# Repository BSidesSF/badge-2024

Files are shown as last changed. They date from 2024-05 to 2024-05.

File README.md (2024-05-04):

# BSidesSF 2024 Badge

| [Readme](README.md) | [Using the Badge](docs/BADGE.md) | [Playing the Game](docs/GAME.md) | [Software Development](docs/DEVELOP.md) | [Badge Hardware](docs/HARDWARE.md) |
| --- | --- | --- | --- | --- |

## Badge Game

The 2024 BSidesSF Badge is designed for playing the Attribution Game.
Similar to the board game Clue or some versions of Carmen Sandiego,
you need to figure out who the threat actor, attack tool, and victim
are for each round of the game. You do this by trading cards (or
'clues') as well as your self-entered alibi name with others
at the conference.

## Attribution Game basics

In order to play in the Attribution Game, you will need to enter a name or handle when you first turn on your badge. This will stay through power cycles. It can be cleared in your settings which will force you to enter a new one.

To trade cards with someone, scroll left or right until you get to the "BSidesSF '24" screen.
Once there, press the toggle up, and place your badge edge at the top of the screen against
the same badge edge of the person you are trading with. You should see once your card has
been transmitted and you have received a card from them.

You can check your collected cards by scrolling right from the "Badge '24" screen.

When you collect enough cards, the one remaining is the solution that completes the phrase. There are 6 games to play through - try them all!

Please see [Playing the Game](docs/GAME.md) for more details

## Repo Contents

This repository contains the hardware and software for
the badge and game. We hope it is useful for those who wish to hack
the badges and game, anyone who wants to use the badge to learn some
circuitpython, as well as others who might like to reuse some or all
of it for other projects.

The badge hardware was designed and produced by @securityfitz, as a favor to BSidesSF using a Labscon badge as a base design.
Ths badge software is a fork of the Labscon badge software, further mangled by @rlc4, @lanrat, and @securelyfitz

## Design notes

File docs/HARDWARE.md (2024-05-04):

# Hardware

| [Readme](../README.md) | [Using the Badge](BADGE.md) | [Playing the Game](GAME.md) | [Software Development](DEVELOP.md) | [Badge Hardware](HARDWARE.md) |
| --- | --- | --- | --- | --- |

`/hardware/` contains the kicad board design files and full details about
design and manufacturing. The hardware on the badge includes:

-  Raspberry Pi 2040, derived from the seeed xiao 2040
-  16MB spi flash for code and files
-  128x64 OLED display with SH1106 controller over I2C
-  IRDA PHY used directly on UART.
-  5-way d-pad for input
-  2 neopixel LEDs
-  AA battery plus boost voltage converter
-  USB-C connector plus vreg for usb power
-  power switch to switch between USB and Battery power
-  test points for reset, boot, and swd

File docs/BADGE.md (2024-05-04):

# Using the Badge

| [Readme](../README.md) | [Using the Badge](BADGE.md) | [Playing the Game](GAME.md) | [Software Development](DEVELOP.md) | [Badge Hardware](HARDWARE.md) |
| --- | --- | --- | --- | --- |

## Setup

When you first power on your badge it will give you a brief intro to
the badge and the game, then it will ask you for your contact info.
This could be a handle, email address, or any other string that will
be shared with everyone you interact with. Use the up and down but
tons to choose letters, left and right to move through the string,
and press the button to set your name. (it can be changed later)

## Navigating

- Left and Right switches between:
  - Home page
  - Alibis page, which shows all the people you've traded contact info and clues with
  - Clues page, which shows all the cards you've collected so far
  - Settings, which allow you to change badge features
- Up takes you to trade mode, described below
- Down puts the badge to sleep, which also happens automatically after a few
   seconds
- Pressing the center button usually gives you more details about whatever you're highlighting.

### Trading

Your badge has an infrared transceiver. Press the 'up' button to enter trade mode.
The badge will:

- transmit your clue as well as your contact information
- listen to receive someone elses card and contact info
- verify the cryptographic signature on the clue
- tell you the result of the trade.
  After the trade, you should be able to see the information in your Contacts an
  Cards pages.

### Winning

The real prize isn't attribution but the contacts and friends we made along the way.
If you happen to have collected enough info to attribute the attack, your badge will
tell you. Find a game organizer to validate your win.

### Multiple rounds

The first round of the game will be pretty easy with only a few trades needed to
attribute. Once a game is complete, the game controller will transmit a packet to
advance the game to the next round, which will propagate to everyone when they
trade clues. Each round will have a different set of cards/clues and a different
attack to attribute.

## After the conference

This badge can work as a simple circuitpython learning platform. The best source
of information about circuitpython is available on Adafruit, including a [Welcome
to CircuitPython guide](https://learn.adafruit.com/welcome-to-circuitpython/overview)

The best place to start tinkering is probably with some neat light animations on
the RGB LED on the badge. Adafruit
[has an example](https://github.com/adafruit/Adafruit_Learning_System_Guides/blob/main/Welcome_to_CircuitPython/code.py)
on how to use this RGB LEDs.

For working interactively with a python CLI, plug your badge in with a USB cable,
and connect to the serial port that shows up.

For writing your own circuitpython programs, you need to modify the code.py
file you can find on the drive that shows up when you plug in the USB cable.
Every time you save the file, the board will reset and start running your code.

If you've somehow messed up your badge, you can follow the process below to
flash a fresh copy of circuitpython and/or the game code.

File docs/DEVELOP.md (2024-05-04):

# Develop with BSidesSF Badge 2024

| [Readme](../README.md) | [Using the Badge](BADGE.md) | [Playing the Game](GAME.md) | [Software Development](DEVELOP.md) | [Badge Hardware](HARDWARE.md) |
| --- | --- | --- | --- | --- |

## Developing for the badge

Version: CircuitPython 9.0.4; Seeeduino XIAO RP2040

Make sure you use version compatible libraries

### Installing CircuitPython

When the RP2040 boots, it checks for valid data in the spi flash. If it doesn't,
it boots into USB boot-loader mode and shows up as a drive labeled RPI-RP2.
[Download and copy the .UF2 file](https://circuitpython.org/board/seeeduino_xiao_rp2040/)
to the drive and it will reboot into CircuitPython.
If you need to reinstall for any reason, short the 'BOOT' test pads while resetting
the RP2040 and it will go back to the boot-loader mode.

### Installing The Attribution Game

Once CircuitPython is installed, when the badge is plugged in it will show
both a serial port and a drive labeled CIRCUITPY. Copy the entire contents
of `/software/` in this repository to that drive. the badge will reboot and run the code.

### Provisioning the game data

The `/config/` directory contains some text files with data specific to
the game. These will be copied along with the rest of the code:

- genfiles generates a pair of keys, and creates 50 variations of game*.csv files
- game*.csv has all the possible clues for each game, and is provisioned with one signed clue per game
- seed.txt needs to be filled with a seed for the random choice of solutions
- priv.json and pub.json are generated by genfiles and contain the game keys which can be used to authenticate the signed
  clues you receive. This is generated by the controller, the public key is copied to all badges

Details about the hardware can be found in [HARDWARE](docs/HARDWARE.md)

## Software

- `/software/` contains the code on the badge
- `/flash/` contains files and tools for automatically flashing badges
- `/config/` contains tools to generate all of the encrypted badge configurations

### Architecture

Most functions are wrapped inside classes with the priority to make the top level
code more clean and readable versus sticking to a clean object model.

All functions should be non-blocking and quick to make sure the UI doesn't get
frozen and button presses don't get missed. This means stuff like checking for
enough UART valid data before reading it, and scheduling timed actions based on
timestamps instead of sleep() calls

#### Dependencies

- core circuitpython libraries: time,board,busio,pulseio,digitalio,displayio,
  terminalio
- additional adafruit libraries in `/software/lib/`: debouncer,
  ticks, displayio_ssh1106, imageload, display_text

#### Support modules

-  Fake_IRDA.py wraps the UART interface, handles enabling/disabling the
   IRDA enable pin, and stuffing/unstuffing the bytes that are transmitted
   to work with the IRDA phy in the nonstandard way we use it
-  Five_Way_Dpad.py wraps the dpad with the Adafruit Debouncer including
   all setup and a few helper functions for checking all buttons at once. The
   non-blocking update() function needs to be run periodically to capture all
   button presses.
-  sh1106_ui.py/ssd1306.py wraps the I2C display interface, handles the overall display
   view, and creates a separate group for each of the navigation pages. The
   non-blocking show() function should be called periodically to make sure the
   correct view is displayed and to manage the transition animations
-  disp.py wraps the functionality of the pages. The class handles initialization,
   managing the display view, underlying data and operations. Most of this is
   handled in a non-blocking update() function that returns the next state

## Screen

* https://www.arduino.cc/reference/en/libraries/oled-ssd1306-sh1106/
* https://docs.circuitpython.org/projects/displayio_sh1106/en/latest/api.html

Driven by: https://docs.circuitpython.org/en/latest/shared-bindings/displayio/

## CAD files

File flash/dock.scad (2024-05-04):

/* badge programming dock
right now, only a few parameters for making a multi-dock
can be mounted with M.3 screws and bolts
USB held in place with M.2 set screw

todo: more parameters; upright orientation; badge origin at usb port; dock base at z=0; round corners
*/

xpitch=10;
ypitch=20;
zpitch=70;
rows=7;
cols=1;
//wall_thickness=2
//badgex=
//badgey=
//badgez=

module badge(){
    union(){
        //pcb edge track
        linear_extrude(68)
        polygon(points=[
        [0,0],
        [126,0],
        [126,100],
        [28,2],
        [0,2]
        ]);
        //battery cutout
        translate([0,-3,4])
            cube([126,23,60]);        
        //usb port
        translate([-80,0.5,34-5.5])
            cube([80,6.5,11]);
        //power switch
        translate([-2,0,45])
            cube([2,5,5]);
        //usb set screw
        screwhole([-6,15,34],[90,0,0],6.5,3);
        //mounting holes
//        screwholes();
        }
}

module badgearray(rows=1,cols=1){
  for (i=[0:rows-1])
    for (j=[0:cols-1])
      translate([-i*xpitch,i*ypitch,j*zpitch])
    badge();
}

module screwhole(origin,orientation,d1=7,d2=4){
  translate(origin)
    rotate(orientation){
      //larger hex inset hole for head/bolt
      cylinder(h=6, d=d1,center=true,$fn=6);
      //smaller hole for shaft
      cylinder(h=100, d=d2,center=true,$fn=12);
    }
}

module screwholes(){
    //bottom
    screwhole([0,10,14],[0,90,0]);
    screwhole([0,10,68-14],[0,90,0]);
    //left
    screwhole([25,10,4],[0,0,0]);
    screwhole([5,10,4],[0,0,0]);
    //right
    screwhole([25,10,64],[0,0,0]);
    screwhole([5,10,64],[0,0,0]);
}

module multibadgedock(rows=1,cols=1){
  difference(){
    union(){
      translate([0,-2,-2])
        linear_extrude(zpitch*cols+2)
          polygon(points=[
            [45,0],
            [-rows*xpitch,0],
            [-rows*xpitch,ypitch*rows-1],
            [45-rows*xpitch,ypitch*rows-1]
          ]);
    }
    //carve out the badges
    badgearray(rows,cols);
    //clip the pointy top
    translate([43,-2,-2])cube([10,10,zpitch*cols+4]);
  }
}

single=true;
single=false;
dock=true;
//dock=false;

if (single){rows=1;cols=1;}
if (dock){
    multibadgedock(rows,cols);
}else{
    badgearray(rows,cols);
}

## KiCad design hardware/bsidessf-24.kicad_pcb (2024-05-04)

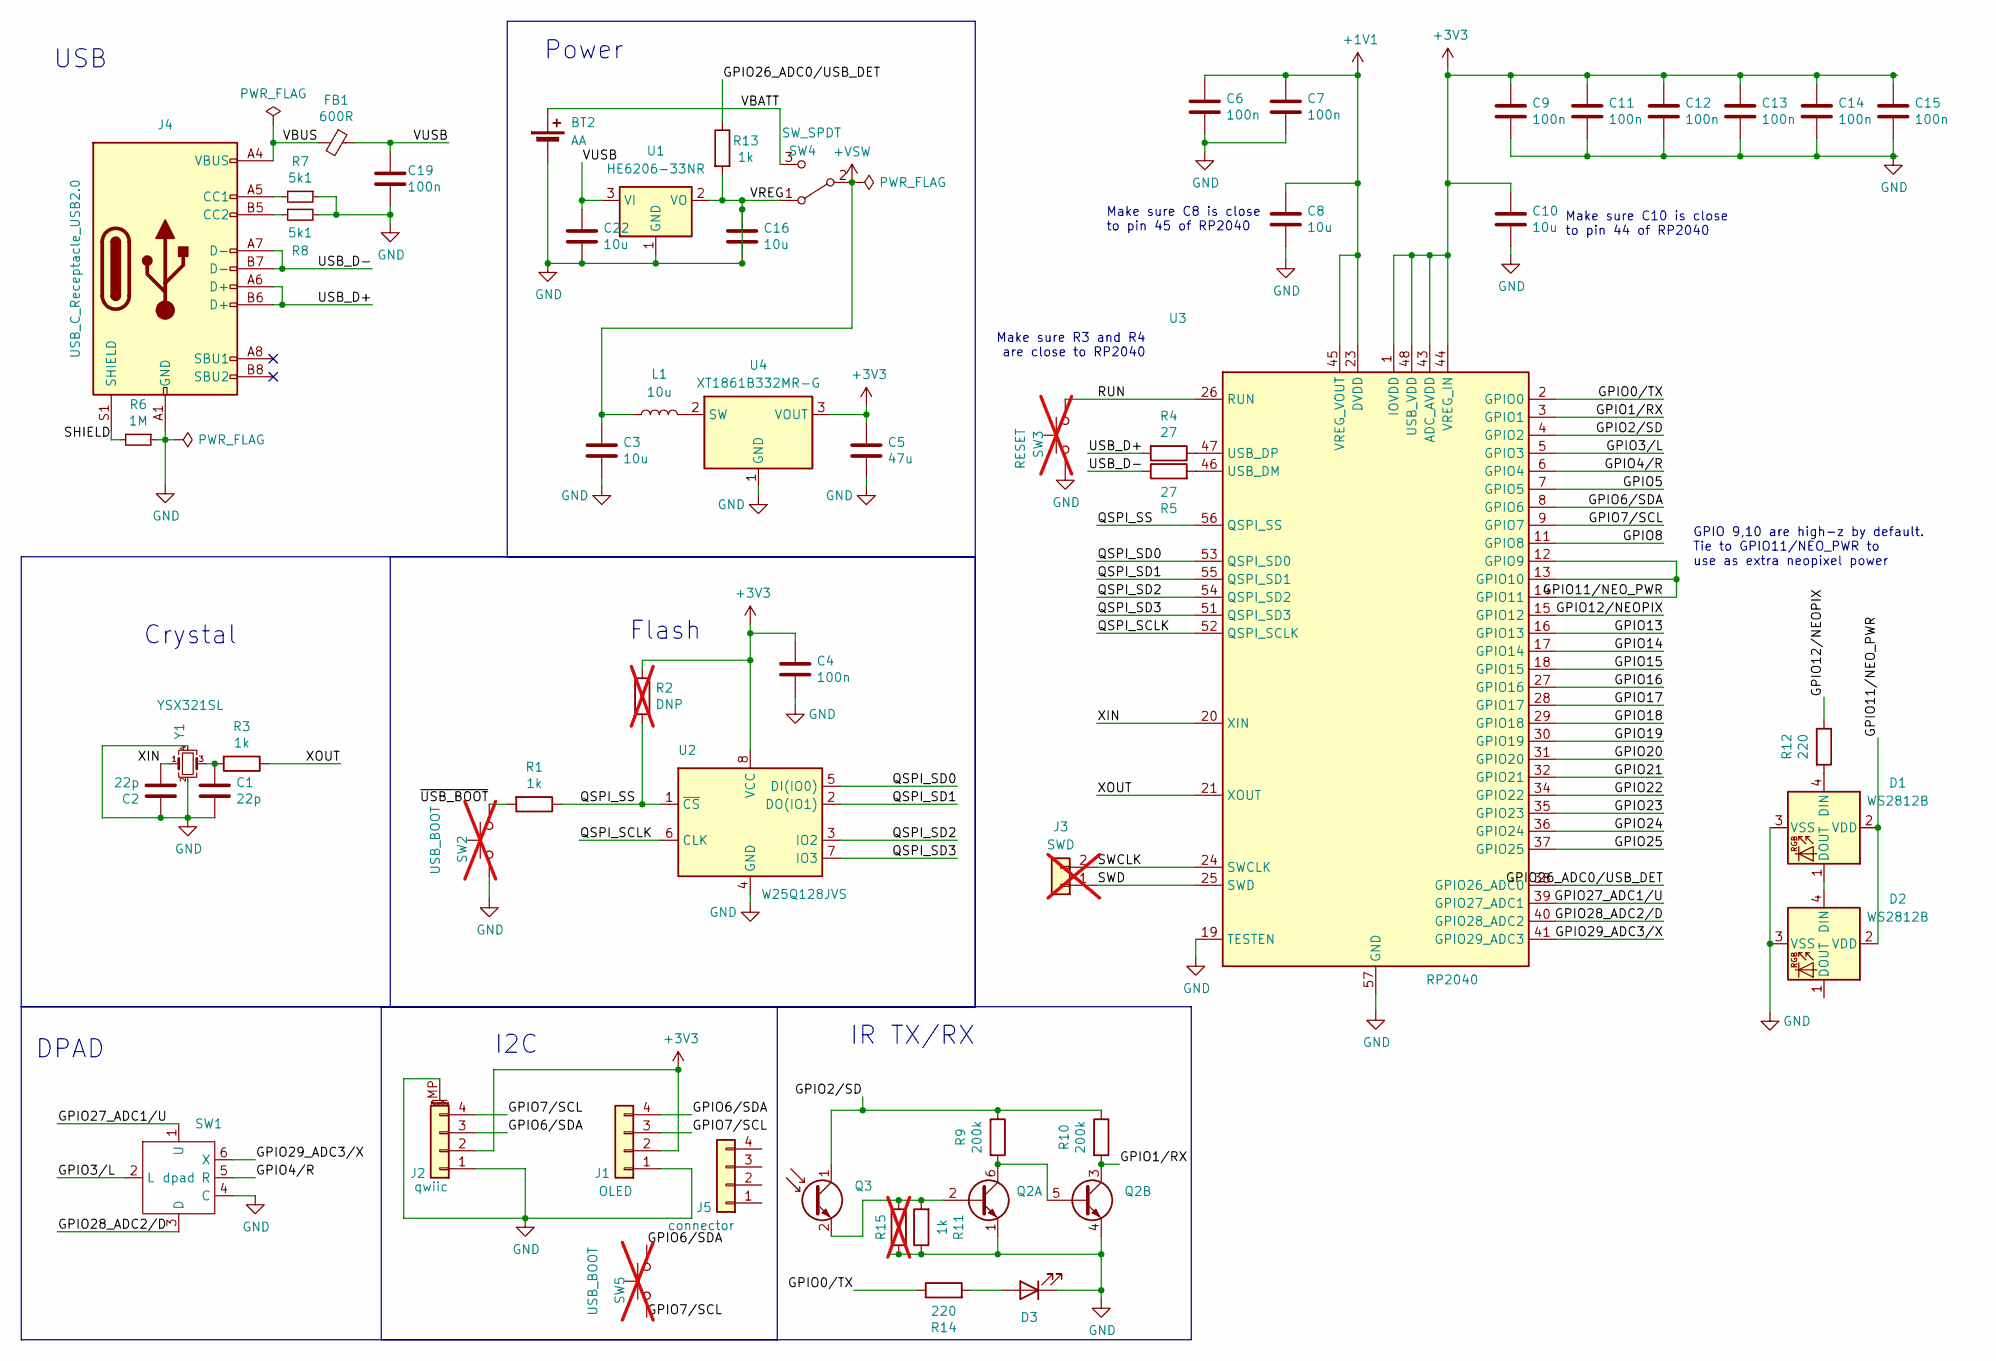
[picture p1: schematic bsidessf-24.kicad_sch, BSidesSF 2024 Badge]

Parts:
BT2: AA; BatteryHolder_Keystone_2460_1xAA; LCSC C5290181
C1, C2: 22p; C_0402_1005Metric; LCSC C106203
C3, C8, C10, C16, C22: 10u; C_0402_1005Metric; LCSC C15525
C4, C6, C7, C9, C11, C12, C13, C14, C15, C19: 100n; C_0402_1005Metric; LCSC C100072
C5: 47u; C_0805_2012Metric; LCSC C16780
D1, D2: WS2812B; LED_WS2812B_PLCC4_1.0x1.0mm; LCSC C5349953
D3: IR12-21C/TR8; IR12-21C-TR8; LCSC C53672
FB1: 600R; L_0402_1005Metric; LCSC C76886
J1: OLED; PinHeader_1x04_P2.54mm_Vertical; LCSC C5248080
J2: qwiic; JST_SH_SM04B-SRSS-TB_1x04-1MP_P1.00mm_Horizontal; LCSC C7433425
J3: SWD; SolderJumper-2_P1.3mm_Open_RoundedPad1.0x1.5mm; LCSC DNP; not fitted
J4: USB_C_Receptacle_USB2.0; USB_C_Receptacle_HRO_TYPE-C-31-M-12; LCSC C2927038
J5: connector; PinHeader_1x04_P2.54mm_Vertical; LCSC C2902691
L1: 10u; L_1008_2520Metric; LCSC C602018
Q2: BC847BS; SOT-363_SC-70-6; LCSC C5380687
Q3: PT12-21B/TR8; PT12-21B-TR8; LCSC C264383
R1, R3, R11, R13: 1k; R_0402_1005Metric; LCSC C11702
R2, R15: DNP; R_0402_1005Metric; LCSC DNP; not fitted
R4, R5: 27; R_0402_1005Metric; LCSC C25100
R6: 1M; R_0402_1005Metric; LCSC C26083
R7, R8: 5k1; R_0402_1005Metric; LCSC C25941
R9, R10: 200k; R_0402_1005Metric; LCSC C25764
R12, R14: 220; R_0402_1005Metric; LCSC C25091
SW1: dpad; 10x10x10x9-6P-WX; LCSC C2858290
SW2, SW5: USB_BOOT; SolderJumper-2_P1.3mm_Open_RoundedPad1.0x1.5mm; LCSC DNP; not fitted
SW3: RESET; SolderJumper-2_P1.3mm_Open_RoundedPad1.0x1.5mm; LCSC DNP; not fitted
SW4: SW_SPDT; SW_SPDT_PCM12; LCSC C319020
U1: HE6206-33NR; SOT-23-3; LCSC C5199441
U2: W25Q128JVS; SOIC-8_5.23x5.23mm_P1.27mm; LCSC C97521
U3: RP2040; QFN-56-1EP_7x7mm_P0.4mm_EP3.2x3.2mm; LCSC C2040
U4: XT1861B332MR-G; SOT-23; LCSC C236396
Y1: YSX321SL; Crystal_SMD_3225-4Pin_3.2x2.5mm; LCSC C9002

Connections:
+1V1: C6.1, C7.1, C8.1, U3.23 (DVDD), U3.45 (VREG_VOUT), U3.50 (DVDD)
+3V3: C4.1, C5.1, C9.1, C10.1, C11.1, C12.1, C13.1, C14.1, C15.1, J1.2, J2.2, R2.1, U2.8 (VCC), U3.1 (IOVDD), U3.10 (IOVDD), U3.22 (IOVDD), U3.33 (IOVDD), U3.42 (IOVDD), U3.43 (ADC_AVDD), U3.44 (VREG_IN), U3.48 (USB_VDD), U3.49 (IOVDD), U4.3 (VOUT)
+VSW: C3.1, L1.1, SW4.2 (B)
/GPIO0/TX: R14.1, U3.2 (GPIO0)
/GPIO1/RX: Q2.3 (C2), R10.2, U3.3 (GPIO1)
/GPIO2/SD: Q3.1 (C), R9.1, R10.1, U3.4 (GPIO2)
/GPIO3/L: SW1.2 (L), U3.5 (GPIO3)
/GPIO4/R: SW1.5 (R), U3.6 (GPIO4)
/GPIO5: U3.7 (GPIO5)
/GPIO6/SDA: J1.4, J2.3, SW5.1, U3.8 (GPIO6)
/GPIO7/SCL: J1.3, J2.4, SW5.2, U3.9 (GPIO7)
/GPIO8: U3.11 (GPIO8)
/GPIO11/NEO_PWR: D1.2 (VDD), D2.2 (VDD), U3.12 (GPIO9), U3.13 (GPIO10), U3.14 (GPIO11)
/GPIO12/NEOPIX: R12.1, U3.15 (GPIO12)
/GPIO13: U3.16 (GPIO13)
/GPIO14: U3.17 (GPIO14)
/GPIO15: U3.18 (GPIO15)
/GPIO16: U3.27 (GPIO16)
/GPIO17: U3.28 (GPIO17)
/GPIO18: U3.29 (GPIO18)
/GPIO19: U3.30 (GPIO19)
/GPIO20: U3.31 (GPIO20)
/GPIO21: U3.32 (GPIO21)
/GPIO22: U3.34 (GPIO22)
/GPIO23: U3.35 (GPIO23)
/GPIO24: U3.36 (GPIO24)
/GPIO25: U3.37 (GPIO25)
/GPIO26_ADC0/USB_DET: R13.1, U3.38 (GPIO26_ADC0)
/GPIO27_ADC1/U: SW1.1 (U), U3.39 (GPIO27_ADC1)
/GPIO28_ADC2/D: SW1.3 (D), U3.40 (GPIO28_ADC2)
/GPIO29_ADC3/X: SW1.6 (X), U3.41 (GPIO29_ADC3)
/QSPI_SCLK: U2.6 (CLK), U3.52 (QSPI_SCLK)
/QSPI_SD0: U2.5 (DI(IO0)), U3.53 (QSPI_SD0)
/QSPI_SD1: U2.2 (DO(IO1)), U3.55 (QSPI_SD1)
/QSPI_SD2: U2.3 (IO2), U3.54 (QSPI_SD2)
/QSPI_SD3: U2.7 (IO3), U3.51 (QSPI_SD3)
/QSPI_SS: R1.1, R2.2, U2.1 (~CS), U3.56 (QSPI_SS)
/RUN: SW3.1, U3.26 (RUN)
/SHIELD: J4.S1 (SHIELD), R6.2
/SWCLK: J3.2, U3.24 (SWCLK)
/SWD: J3.1, U3.25 (SWD)
/USB_D+: J4.A6 (D+), J4.B6 (D+), R4.2
/USB_D-: J4.A7 (D-), J4.B7 (D-), R5.1
/VBATT: BT2.1 (+), SW4.3 (C)
/VBUS: FB1.2, J4.A4 (VBUS), J4.A9 (VBUS), J4.B4 (VBUS), J4.B9 (VBUS)
/VREG: C16.1, R13.2, SW4.1 (A), U1.2 (VO)
/VUSB: C19.1, C22.1, FB1.1, U1.3 (VI)
/XIN: C2.2, U3.20 (XIN), Y1.1
/XOUT: R3.1, U3.21 (XOUT)
/~USB_BOOT: R1.2, SW2.1
GND: BT2.2 (-), C1.2, C2.1, C3.2, C4.2, C5.2, C6.2, C7.2, C8.2, C9.2, C10.2, C11.2, C12.2, C13.2, C14.2, C15.2, C16.2, C19.2, C22.2, D1.3 (VSS), D2.3 (VSS), D3.2 (K), J1.1, J2.1, J2.MP (MountPin), J4.A1 (GND), J4.A12 (GND), J4.B1 (GND), J4.B12 (GND), Q2.1 (E1), Q2.4 (E2), R6.1, R7.1, R8.2, R11.1, R15.1, SW1.4 (C), SW2.2, SW3.2, U1.1 (GND), U2.4 (GND), U3.19 (TESTEN), U3.57 (GND), U4.1 (GND), Y1.2, Y1.4
unnamed: C1.1, R3.2, Y1.3
unnamed: D1.4 (DIN), R12.2
unnamed: D1.1 (DOUT), D2.4 (DIN)
unnamed: D3.1 (A), R14.2
unnamed: J4.A5 (CC1), R7.2
unnamed: J4.B5 (CC2), R8.1
unnamed: Q2.2 (B1), Q3.2 (E), R11.2, R15.2
unnamed: Q2.5 (B2), Q2.6 (C1), R9.2
unnamed: R5.2, U3.46 (USB_DM)
unnamed: R4.1, U3.47 (USB_DP)
unnamed: L1.2, U4.2 (SW)

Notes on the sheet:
DPAD
Make sure C10 is close to pin 44 of RP2040
Make sure C8 is close to pin 45 of RP2040
IR TX/RX
USB
I2C
Make sure R3 and R4 are close to RP2040
Flash
Crystal
Power
GPIO 9,10 are high-z by default. Tie to GPIO11/NEO_PWR to use as extra neopixel power

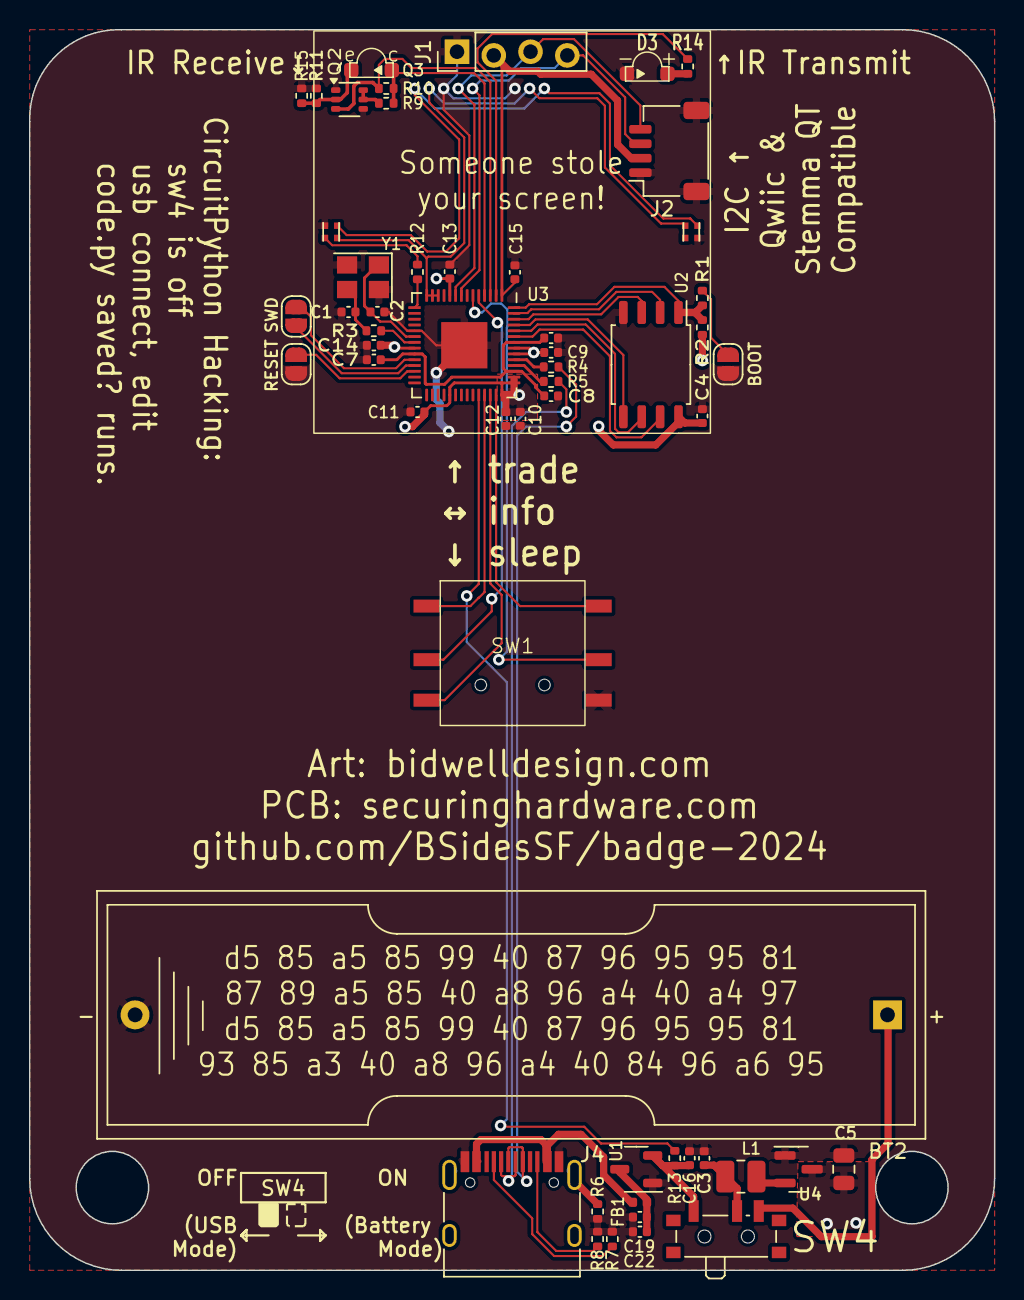
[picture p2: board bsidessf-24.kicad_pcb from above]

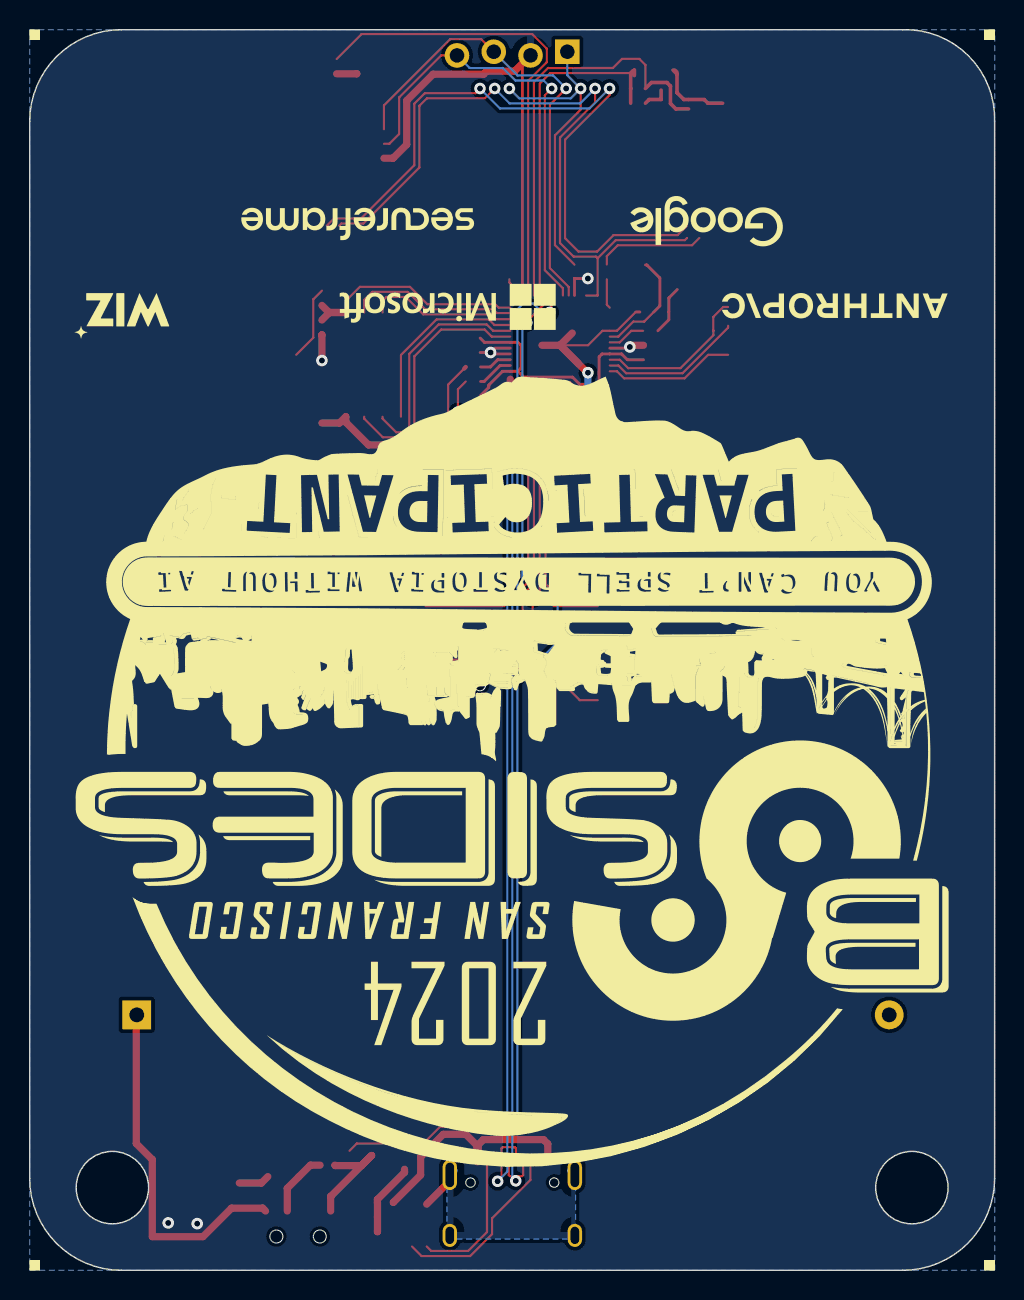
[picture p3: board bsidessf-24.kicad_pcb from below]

Board: 2 copper layers, 66.7 x 85.7 mm, 58 parts (2 on the bottom side), 47 nets.

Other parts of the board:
OSHW: OSHW-Logo2_14.6x12mm_SolderMask
SH-Logo: SH-logo-mask
black-silk: black-silk
red-silk: red-silk

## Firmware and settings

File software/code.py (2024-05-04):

import time
from ssd1306_ui import ssd1306ui
from five_way_pad import FiveWayPad
from disp import disp

from leds import led_control
from home import home
from clues import clues
from alibis import alibis
from settings import settings
from trade import trade
from sleep import sleep
from game import game_data
import gc

BLACK=0x000000
WHITE=0xFFFFFF



#display, dpad, and leds wrap access to physical I/O
display=ssd1306ui()
dpad=FiveWayPad()
leds=led_control()
gc.collect()

l_disp = disp(display.homegroup, dpad)

#instantiate home first, since it manages OOB.
# homepage=home(display.homegroup,dpad)
homepage=home(l_disp, dpad)

#next, load game data since we know we have a username
game=game_data(0)
homepage.game=game
gc.collect()

#finally, create the other view pages, most of which need to access
#a single display group, dpad state, and game data
clues_page=clues(display.cluesgroup,dpad,game)
settings_page=settings(display.settingsgroup,dpad,game,leds)
alibis_page=alibis(l_disp,dpad,game)
trade_page=trade(dpad,game,l_disp)
sleep_page=sleep(display,dpad,leds)
gc.collect()

#start out on the home page
page="home"
last_page="home"

# TODO unused
SLEEP_TIMEOUT=90

# ToDo: If not configured, run through configuration steps
while True:
    #update leds and display
    leds.animate()
    gc.collect()
    if page!=0: display.show(page)

    #scan inputs
    dpad.update()

    #sleep if it's been a while - except trade page
    if dpad.duration() > settings_page.timeout and page != "trade":
        page=sleep_page.update()

    #if a button is pressed, handle it
    if not dpad.pressed():
        time.sleep(0.001)
    elif page == "home":
        last_page=page
        page=homepage.update()
    elif page == "settings":
        last_page=page
        page=settings_page.update()
    elif page == "alibis":
        last_page=page
        page=alibis_page.update()
    elif page == "clues":
        last_page=page
        page=clues_page.update()
    elif page == "trade":
        page=trade_page.update()
    elif page == "sleep":
        page=sleep_page.update()
    else: page=last_page

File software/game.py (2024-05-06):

import circuitpython_csv
import gc
#from binascii import crc32
from binascii import crc32,a2b_base64
from json import loads
from adafruit_rsa import PublicKey

# this class contains all the data relevant to the game. It manages
# loading the data from files, updating it, and writing it back.
class game_data:
    # game_num=0  # set in __init__
    myclue=None
    signature=""
    # myname=None # set in __init__ via call to read_myname()
    mytxval=None
    game_file="data/game1.csv"
    alibi_file="data/alibis.csv"

    #initialize all the data. Read all 3 files and load into memory
    def __init__(self,game_num=0):
        self.game_num=game_num
        self.read_name()
        self.read_alibis()
        self.pubkey=self.read_pubkey()
        print(self.pubkey)
        self.game_file="data/game"+str(game_num)+".csv"
        self.read_clues()

    #check a clue, and if valid for this game, add it to the structure.
    def check_clue(self,newclue,alibi):
        #if we haven't met the alibi before, a them to the list, and flush to disk
        if alibi not in self.alibis.keys():
            self.alibis[alibi]=[newclue]
        # if we have, append the clue to the list of clues
        else:
            print(f"Alibi {alibi} already known, appending")
            #check for duplicate clue in this list
            if newclue not in self.alibis[alibi]:
                self.alibis[alibi].append(newclue)
        self.write_alibis()
        #iterate over all clues. If we have the clue, mark it collected, log the alibi,
        #flag it so the display knows to update it, and flush to disk
        match=False
        for typename,cluetype in self.clues.items():
            if newclue in cluetype["known"]:
                print("clue already shared by ",cluetype["known"][newclue]," but thanks anyway "+alibi)
                match=True
                break
            elif len(cluetype["unknown"])>1 and newclue in cluetype["unknown"]:
                print("new clue!",newclue)
                cluetype["known"][newclue]=alibi
                del cluetype["unknown"][newclue]
                self.check_for_solution(typename,cluetype)
                cluetype["updated"]=True
                match=True
                break
        if match : 
            self.write_clues()
            return newclue
        return False

    #load name from file - if it's not there, set to unknown
    #note that we don't do the oob flow here because that needs
    #control of display we don't want in the data storage class.
    def read_name(self):
        try:
            with open("data/myname.txt",'r') as file:
                self.myname=file.readline().rstrip()
                print("hello",self.myname)
        except OSError:
            print("Error reading name from data/myname.txt")
            self.myname="unknown"

    # clear name and write to file
    def wipe_name(self):
        self.myname=""
        self.write_name()

    #open the name file and write out to it
    def write_name(self):
        try:
            with open("data/myname.txt", 'w') as fhandle:
                fhandle.write(self.myname)
        except OSError:
            print("Error writing name file")
            return False
        return True

    def check_for_solution(self,typename,cluetype):
        if len(cluetype["unknown"]) == 1:
            answer=list(cluetype["unknown"].keys())[0]
            self.solution_string=self.solution_string.replace("["+typename+"]",answer)
            print(self.solution_string)
            self.unsolved-=1
            print("#unsolved: ", self.unsolved)
            if self.unsolved==0:
                print("full solution!!")

    #read csv file of clues for this game. Can be called again
    #to change to a different game number
    def read_clues(self):
        try:
            with open(self.game_file, 'r') as file:
                csv=circuitpython_csv.reader(file)
                #dict to hold clue types which hold clues
                self.clues={}
                #first value tells us what type of clue it is
                self.solution_string="#T used #A against #V"
                for row in csv:
                    if row[0] == "*": 
                        #print(row)
                        self.myclue=row[1]
                        #print(self.myclue,row[2],self.signature)
                        #todo: this should be added to game files as row[2]
                        #self.signature=a2b_base64(row[2])
                        self.signature=row[2]
                        #self.signature="none
                    elif row[0] == "#":
                        self.solution_string=row[1]
                        print(self.solution_string)
                    #make sure we have enough data
                    elif len(row) > 3:
                        status="unknown" if row[3]=="" else "known"
                        #if we haven't seen this cluetype before, create the dict
                        if row[0] not in self.clues:
                            self.clues[row[0]]={"known":{},"unknown":{},"updated":True}
                        #and enter the clue into the dict
                        self.clues[row[0]][status][row[1]]=row[3]
            # count of unsolved categories
            self.unsolved=len(self.clues)
            # check for solutions, count unsolved categories
            for typename,cluetype in self.clues.items():
                self.check_for_solution(typename,cluetype)
                cluetype["updated"]=True
            print("#unsolved: ", self.unsolved)
                
            print(self.clues)
            #add our clue to the table
            self.check_clue(self.myclue,self.myname)
            #calculate the message we'll send when we trade.
            transmit_data=bytearray(",".join([self.myname,str(self.game_num),self.myclue,str(self.signature)]),'utf8')
            #calculate CRC
            crc = hex(crc32(transmit_data))#[2:]
            #crc = str(crc32(transmit_data))
            #self.mytxval=transmit_data+crc
            self.mytxval=transmit_data+bytearray(","+crc,'utf8')
            print(f"{self.mytxval}")
        except OSError:
            print("Error reading from file:", self.game_file)

    #essentially 'resets' the current game, wiping all clues then adding yours back
    def wipe_clues(self):
        ## new clue structure
        for cluetype in self.clues.values():
            for clue in cluetype["known"]:
                cluetype["unknown"][clue]=""
            cluetype["known"]={}
            cluetype["updated"]=True
        print(self.clues)
        self.check_clue(self.myclue,self.myname)
        self.write_clues()
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

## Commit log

2024-05-04 Initial public commit
    [bsidessf-24.kicad_pcb, bsidessf-24.kicad_sch, dock.scad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]
2024-05-05 Update game.py
    Fix ValueError crash
    [game.py]
